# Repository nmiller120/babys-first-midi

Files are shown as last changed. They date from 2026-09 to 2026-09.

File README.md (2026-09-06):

# Baby's First MIDI

A Fisher-Price piano hacked into a MIDI controller while preserving the toy's original functionality.

## Hardware

- Pimoroni Tiny 2350 (RP2350, 3.3 V logic)
- Fisher-Price Kick & Play-style piano
- Teenage Engineering EP-133 K.O. II as the initial MIDI target
- 3.5 mm TRS Type A MIDI output
- Two 10k potentiometers for octave/group and scale selection

## Current controller layout

### Piano keys

Five active-high digital inputs are mapped to the Fisher-Price piano keys:

| Tiny 2350 GPIO | Key |
| --- | --- |
| GP1 | Key 1 |
| GP2 | Key 2 |
| GP3 | Key 3 |
| GP4 | Key 4 |
| GP5 | Key 5 |

The inputs currently use the RP2350 internal pull-downs. A press sends MIDI Note On and releasing the key sends MIDI Note Off. Notes sustain for as long as a key is held, and multiple keys can be held simultaneously for polyphonic MIDI.

The key inputs use a 30 ms software debounce.

### A0 - octave / KO II group selector

A 10k potentiometer connected to A0 (GP26 / ADC0) selects the C-root octave:

| Setting | Root MIDI note | KO II group |
| --- | ---: | --- |
| C2 | 36 | A |
| C3 | 48 | B |
| C4 | 60 | C |
| C5 | 72 | D |

This uses the KO II's fixed MIDI note ranges to make the pot function as a physical A/B/C/D group selector.

### A1 - scale selector

A second 10k potentiometer connected to A1 (GP27 / ADC1) selects the interval mapping for the five keys:

| Setting | Five-key mapping |
| --- | --- |
| Chromatic | C, C#, D, D#, E |
| Major | C, D, E, F, G |
| Minor | C, D, Eb, F, G |
| Minor Pentatonic | C, Eb, F, G, Bb |
| Major Pentatonic | C, D, E, G, A |

The root is always C. The A0 octave selection is added to the interval pattern selected by A1 to produce the final MIDI note.

## Potentiometer calibration and filtering

Bench testing showed that both pots reach approximately 56,000 at the top of their useful ADC range rather than the full 65,535 returned by MicroPython's `read_u16()`.

The selector logic therefore uses a calibrated range:

    POT_ADC_MIN = 1000
    POT_ADC_MAX = 56000

Readings outside that range are clamped to the nearest endpoint. This provides usable dead zones at both physical ends of the pots and ensures the first and last selector positions are easy to reach.

To prevent ADC noise from causing selector chatter near a boundary, two filters are applied:

    POT_HYSTERESIS = 2000
    POT_DEBOUNCE_MS = 150

A pot must first move beyond the hysteresis boundary and then remain in the new discrete state for at least 150 ms before the selection is accepted.

The stable filtered selector state is also used when calculating MIDI notes, so debug output and actual MIDI behavior remain synchronized.

## MIDI output

Tiny 2350 UART0 TX is on GP0. MIDI serial runs at 31,250 baud.

The current 3.3 V MIDI transmitter breadboard is:

    Tiny 2350                     TRS Type A MIDI
    ---------                     ---------------
    3V3 --- 20R --- 10R -------- Ring
    GP0 ----------- 10R -------- Tip
    GND                         (not connected)
                                Sleeve: NC

The 20 ohm + 10 ohm series pair is a temporary 30 ohm approximation to the nominal 33 ohm transmitter resistor used in the 3.3 V MIDI circuit.

IMPORTANT: Verify wiring and polarity before connecting an instrument. The KO II uses TRS MIDI Type A.

## LED behavior

The Tiny 2350 onboard RGB LED is used as a MIDI activity indicator. It lights white while one or more notes are being held and turns off when the final active note is released.

## Debug output

During development, `main.py` prints state changes to the MicroPython console.

Changing the octave/group pot produces output similar to:

    OCTAVE | Octave: C4 | KO II Group: C | Root MIDI Note: 60

Changing the scale pot produces:

    SCALE  | Scale: Minor Pentatonic

Pressing a key reports the complete transformation:

    PRESS | Octave: C4 | KO II Group: C | Scale: Minor Pentatonic | MIDI Note: 67

This makes it possible to verify the pot selection, scale mapping, and resulting MIDI note from Thonny without relying solely on the KO II.

## Tests

The `Tests` directory contains development/bench scripts.

- `Test001.py` - initial UART MIDI and onboard LED test.
- `Test002.py` - periodically prints raw A0/A1 ADC readings and approximate voltages for potentiometer testing and calibration.

## Development status

Current development branch: `feature/pot-scale-selection`.

Completed so far:

- Tiny 2350 MicroPython environment
- 31,250 baud MIDI UART output
- TRS Type A KO II MIDI communication
- Five debounced digital key inputs
- Sustained Note On / Note Off behavior
- Polyphonic key handling
- Onboard MIDI activity LED
- Four-position octave / KO II group selection
- Five-position scale selection
- Potentiometer ADC calibration
- Potentiometer hysteresis and time debounce
- Thonny debug logging

Next major hardware step is integrating the Tiny 2350 inputs with the Fisher-Price key signals while preserving the toy's original functionality.

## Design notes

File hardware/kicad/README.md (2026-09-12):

# Baby's First MIDI — KiCad

KiCad hardware design files for Baby's First MIDI.

The Rev A prototype board is routed on two copper layers, with a filled backside
ground zone. Open `babys-first-midi.kicad_pro` so KiCad loads the project rules and
the `BFM` footprint library from `fp-lib-table`.

## DRC repair, 2026-09-11

Starting from placement-only commit `f590c33`, this revision:

- Moves the RJ45 back to the left side, inside the board outline and clear of the
  MIDI jack; moves the MIDI jack away from the lower-right mounting hole.
- Rotates the five MOSFET footprints to provide separate gate, drain and source
  escape paths, then routes all required connections and refills ground copper.
- Preserves every pad number and net assignment from the starting board.
- Fixes silkscreen overlaps, puts hidden values on F.Fab, and stores all seven
  prototype footprint definitions in the project-local `BFM.pretty` library.
- Saves explicit minimum rules: 0.25 mm copper clearance, 0.25 mm track width,
  0.50 mm copper-to-edge clearance, and 0.15 mm silkscreen clearance. Routes use
  0.30 mm tracks. No DRC exclusions or severity suppressions were added.

Validated with KiCad 10.0.6: **0 violations and 0 unconnected items**.
The machine-readable report is `validation/drc.json`. Reproduce from this folder:

```powershell
kicad-cli pcb drc --refill-zones --format json --exit-code-violations --output validation/drc.json babys-first-midi.kicad_pcb
```

This remains the prototype experiment described in the earlier design work:
the connector footprints remain project-specific draft geometries. The clean
result verifies board geometry and connectivity against the PCB net assignments;
it does not certify the remaining connector fit, enclosure fit or schematic parity.

## Populated 3D view

In PCB Editor, use View > 3D Viewer (Alt+3). Models are attached to the board
and to the project footprint library. Resistors and MOSFETs use KiCad's standard
STEP models; install the KiCad 10 3D model library if these do not appear.
The RJ45 uses a drawing-based model. The WH148 pots and Tiny
2350 now use the bundled drawing-based replacement models. Their geometry,
source drawings and remaining estimates are documented in
`3dmodels/MECHANICAL_NOTES.md`.

The WH148 replacement changes the old 3 mm pitch to 5 mm, with 1.3 mm holes.
Pots mount directly, shafts parallel to the board toward the top edge. The Tiny
footprint's mirrored banks are corrected and the module is rotated and moved
to put USB at the right edge. Routing and ground fill are regenerated while
preserving all numbered pad-to-net assignments. KiCad 10.0.6 DRC reports zero
violations and zero unconnected items; see `validation/drc.json`.

J2 is now the uxcell PJ-320A, using a Keebio STEP model and adapted footprint.
The user-supplied pinout maps MIDI_TIP to pin 4 and MIDI_RING to pin 3; pins 1
(sleeve, as before) and 2 (ring2) are unconnected. The mouth faces the right
edge. See `3dmodels/MECHANICAL_NOTES.md` for source attribution and geometry
limits. The replacement is rerouted and passes DRC with no unconnected items.

J1 now uses BFM:RJ45_FMHXG_AssumedPinout and a drawing-based model, facing the
left edge. The 8 signal holes, 2 locating holes and 2 shield holes follow the
user-supplied drawing. Sequential 1-8 numbering is an explicit prototype
assumption approved by the user, not a verified vendor pinout. Existing numbered
signal nets are preserved; shield pads are unconnected. See
`RJ45_CONTINUITY_CHECK.md` for the precise mapping to check when the parts arrive.
Rerouting and ground refill pass KiCad 10.0.6 DRC: zero violations and zero
unconnected items.

## 2N7000 input buffers

Q1-Q5 now use through-hole 2N7000 MOSFETs with the onsemi 2N7000TA
TO-92 pinout: 1=source (GND), 2=gate (input resistor), 3=drain (GPIO/pull-up).
Datasheet: https://www.onsemi.com/download/data-sheet/pdf/2n7000ta-d.pdf
The local BFM:TO-92_2N7000_SGD footprint derives from KiCad's
TO-92_Inline_Wide footprint. Its 2.54 mm hole spacing requires spreading the
leads; match the flat face to the fabrication outline. The 3D model is the
standard KiCad 10 TO-92_Inline_Wide STEP model.

PCB nets and schematic connections were checked against the previous design
by gate/drain/source function, including the required pin-number remap.
KiCad 10.0.6 DRC reports zero violations and zero unconnected items.
This verifies layout connectivity, not operation with the toy's unmeasured
signal voltage. Verify input switching on the assembled prototype.

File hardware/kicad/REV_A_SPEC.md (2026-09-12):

# Baby's First MIDI — Rev A Electrical Specification

This file is the source-of-truth for the first ERC-checkable KiCad schematic.

## Architecture

External project box. The Pimoroni Tiny 2350 is powered through its onboard USB-C connector.

Signal flow:

Fisher-Price toy -> RJ45 -> 5x MOSFET input buffers -> Tiny 2350 -> TRS MIDI OUT

Two 10k potentiometers connect directly to Tiny 2350 analog inputs.

## RJ45 pin assignment

| RJ45 pin | Signal |
| --- | --- |
| 1 | FPT_C |
| 2 | FPT_D |
| 3 | FPT_E |
| 4 | FPT_F |
| 5 | FPT_G |
| 6 | FPT_COMMON |
| 7 | Spare |
| 8 | Spare |

## Digital input buffers

Five identical 2N7000 channels are used.

For each channel:

- Fisher-Price sense line -> 100k ohm -> 2N7000 gate
- 2N7000 source -> GND
- 2N7000 drain -> Tiny 2350 GPIO
- 3V3 -> 10k ohm pull-up -> drain/GPIO node

This is an inverting open-drain-style buffer stage.

| Key | Tiny 2350 GPIO |
| --- | --- |
| C | GP1 |
| D | GP2 |
| E | GP3 |
| F | GP4 |
| G | GP5 |

## Potentiometers

Both potentiometers are 10k.

| Function | Tiny 2350 pin |
| --- | --- |
| Octave | GP26 / ADC0 / A0 |
| Scale | GP27 / ADC1 / A1 |

Each pot is wired as a 3.3V-to-GND divider with the wiper going to the ADC input.

## MIDI OUT

UART0 TX is GP0 at 31,250 baud.

TRS Type A output:

- 3V3 -> 33 ohm -> Ring
- GP0 -> 33 ohm -> Tip
- Sleeve -> NC

## Power

The Tiny 2350 is powered only through its onboard USB-C connector for Rev A.

No Fisher-Price power is brought into the project box.

## Schematic intent

The KiCad schematic should contain:

- J1: 8-pin RJ45 female connector
- Q1-Q5: 2N7000
- R1-R5: 100k gate resistors
- R6-R10: 10k GPIO pull-ups
- U1: Pimoroni Tiny 2350 module/header representation
- RV1: 10k octave potentiometer
- RV2: 10k scale potentiometer
- R11-R12: 33 ohm MIDI series resistors
- J2: 3.5mm TRS jack
- Explicit 3V3 and GND nets
- No-connect markers on unused RJ45 pins and TRS sleeve where appropriate

Before Gerber generation, the schematic must pass ERC with no unexplained errors and the PCB must pass DRC with no unexplained errors.

## 2N7000 input buffers

Q1-Q5 now use through-hole 2N7000 MOSFETs with the onsemi 2N7000TA
TO-92 pinout: 1=source (GND), 2=gate (input resistor), 3=drain (GPIO/pull-up).
Datasheet: https://www.onsemi.com/download/data-sheet/pdf/2n7000ta-d.pdf
The local BFM:TO-92_2N7000_SGD footprint derives from KiCad's
TO-92_Inline_Wide footprint. Its 2.54 mm hole spacing requires spreading the
leads; match the flat face to the fabrication outline. The 3D model is the
standard KiCad 10 TO-92_Inline_Wide STEP model.

PCB nets and schematic connections were checked against the previous design
by gate/drain/source function, including the required pin-number remap.
KiCad 10.0.6 DRC reports zero violations and zero unconnected items.
This verifies layout connectivity, not operation with the toy's unmeasured
signal voltage. Verify input switching on the assembled prototype.

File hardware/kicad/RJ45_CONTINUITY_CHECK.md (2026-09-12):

# J1 prototype pinout assumption

Selected part: FMHXG RJ45NMCCFC-90D-10, Amazon B0BRQ2R8HW.
The user approved fitting and routing the connector before physical continuity
verification. Geometry follows the supplied component-side drawing. The related
CKMTW family is a reference, not proof of the FMHXG internal wiring.

Numbering is explicitly assumed sequentially across the staggered terminals:
component side viewed from above, connector mouth toward the TOP of this diagram.
This is not a pinout extracted from a verified FMHXG or CKMTW CAD library.

```text
                   MOUTH
       SH                       SH
           locating     locating

             2    4    6    8       nearer the mouth
          1    3    5    7          rear row
```

Coordinates in mm, origin at front mouth center, X right and Y toward rear:

| Assumed contact | X | Y | Board net |
|---|---:|---:|---|
| 1 | -4.445 | 16.79 | FPT_C |
| 2 | -3.175 | 14.25 | FPT_D |
| 3 | -1.905 | 16.79 | FPT_E |
| 4 | -0.635 | 14.25 | FPT_F |
| 5 | 0.635 | 16.79 | FPT_G |
| 6 | 1.905 | 14.25 | FPT_COMMON |
| 7 | 3.175 | 16.79 | Unconnected |
| 8 | 4.445 | 14.25 | Unconnected |

Both shield pads are unconnected. On the carrier the mouth faces LEFT; rotate
the diagram 90 degrees counterclockwise to match the board's top view.

Before PCB ordering, insert a numbered RJ45 breakout plug or known cable into
one loose jack. With a continuity meter, record which solder terminal connects
to each plug contact 1 through 8. Use the breakout's numbering; wire colors alone
can be misleading without knowing its wiring standard. Also check shield tabs
to metal shell, and test-fit the terminal, peg and shield-hole pattern at 1:1.
If the mapping differs, change the footprint numbering and reroute before
manufacture. The clean DRC report does not validate this physical assumption.

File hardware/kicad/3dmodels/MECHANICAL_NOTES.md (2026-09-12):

# Drawing-based replacement models

The WH148 potentiometers and Tiny 2350 now use custom drawing-based models.
The RJ45 now uses a model and footprint built from the supplied mechanical
drawing. Its contact numbering is a user-approved prototype assumption pending
physical checking; see ../RJ45_CONTINUITY_CHECK.md.

## WH148 potentiometers

Source: user's mechanical drawing for the EEEEE kit, Amazon ASIN B0FGD497QN.
The drawing specifies 5 mm terminal pitch, 1.0 x 0.4 mm terminals, a 16.5 mm
housing, 17 mm front plate, 9.2 mm rear-to-shaft datum length, 15 +/- 0.5 mm
shaft length, 6 mm shaft diameter, 18 knurl teeth and an M7 x 0.75 bushing.

The new BFM:WH148_Horizontal_P5.00mm footprint uses 1.3 mm round finished holes
and 2.5 mm pads. These are chosen hole/pad sizes, not manufacturer land-pattern
recommendations. Pin numbers follow the supplied shaft-end view. All existing
pad-to-net assignments are preserved. Direct mounting puts the shafts parallel
to the board, pointing toward its top edge. Pots are 20 mm apart.

Model coordinates: middle terminal at X/Y zero, shaft toward +Y, carrier top
Z=0. A 0.5 mm substrate-to-board seating gap is assumed. Detailed metal tabs,
substrate contours and bends are approximate; thread crests are cosmetic rings.
Model clearances do not account for the user's knob size, enclosure or nuts.

## Tiny 2350

Sources:
- https://shop.pimoroni.com/products/tiny-2350
- https://cdn.shopify.com/s/files/1/0174/1800/files/tiny-2350-mechanical-diagram.pdf?v=1725452657
- https://cdn.shopify.com/s/files/1/0174/1800/files/tiny2350_pinout_diagram.pdf?v=1723124465

The model has an 18 x 21.3 mm PCB, 2.54 mm pitch and 15.24 mm header-bank spacing.
The carrier footprint's previously mirrored banks are corrected. With USB up,
GP0-GP7 run down the right bank, and VBUS/GND/3V3/A3/A2/A1/A0/GND down the left.
On this carrier the module is rotated with USB facing the right board edge.
The module center is (127.25,58) mm. The model includes switches, Qw/ST socket,
USB shell, castellations, labels and underside components.

The mounted model assumes 2.54 mm male header spacers and lifts the bare module
2.54 mm above the carrier. The PCB thickness, component heights, USB internals
and fine details absent from the drawing are visual estimates. This is custom
CAD, not a manufacturer-supplied STEP model or an enclosure-fit certification.

## PJ-320A MIDI jack

J2 now uses the Keebio PJ-320A STEP and a locally adapted footprint:
https://github.com/keebio/Keebio-Parts.pretty/blob/master/3dmodels/PJ-320A.step
https://github.com/keebio/Keebio-Parts.pretty/blob/master/TRRS-PJ-320A.kicad_mod
The MIT license is preserved in LICENSE-Keebio.txt.

The user's supplied uxcell pinout identifies sleeve=1, tip=4, ring1=3, ring2=2.
This overrides the tip/ring2 labels in the upstream footprint. Pin 4 carries
MIDI_TIP and pin 3 carries MIDI_RING. Ring2 (pin 2) is unused; sleeve (pin 1)
remains unconnected, preserving the old design's sleeve treatment. No claim
of complete MIDI electrical compliance or schematic parity is made here.

The footprint retains four plated slots and two locating holes from Keebio.
Its outline was adapted to clear solder mask and the board edge. The connector
faces right at (138,86) mm, with the mouth at the board edge. Its 3D geometry
and locating-hole dimensions come from the community model, not an uxcell
dimensional drawing. The supplied image establishes the electrical pinout.

## Validation

KiCad 10.0.6 loads the board and renders the bundled models. All 26 components
and signal connections are preserved by function (J2 and Q1-Q5 use remapped pin numbers). J2's original tip/ring
nets are remapped by function to pins 4/3. The corrected pad geometry was
rerouted and ground copper refilled. validation/drc.json
reports zero violations and zero unconnected items. Schematic parity and the
remaining draft connector footprints are outside this verification.

## 2N7000 input buffers

Q1-Q5 now use through-hole 2N7000 MOSFETs with the onsemi 2N7000TA
TO-92 pinout: 1=source (GND), 2=gate (input resistor), 3=drain (GPIO/pull-up).
Datasheet: https://www.onsemi.com/download/data-sheet/pdf/2n7000ta-d.pdf
The local BFM:TO-92_2N7000_SGD footprint derives from KiCad's
TO-92_Inline_Wide footprint. Its 2.54 mm hole spacing requires spreading the
leads; match the flat face to the fabrication outline. The 3D model is the
standard KiCad 10 TO-92_Inline_Wide STEP model.

PCB nets and schematic connections were checked against the previous design
by gate/drain/source function, including the required pin-number remap.
KiCad 10.0.6 DRC reports zero violations and zero unconnected items.
This verifies layout connectivity, not operation with the toy's unmeasured
signal voltage. Verify input switching on the assembled prototype.

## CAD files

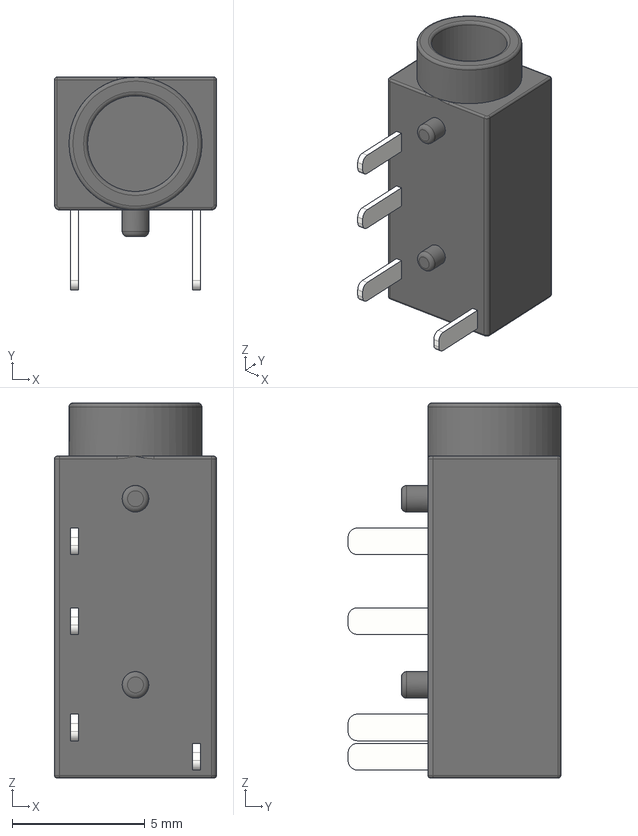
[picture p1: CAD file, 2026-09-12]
hardware/kicad/3dmodels/PJ-320A.step
6.10 x 8.00 x 14.1 mm

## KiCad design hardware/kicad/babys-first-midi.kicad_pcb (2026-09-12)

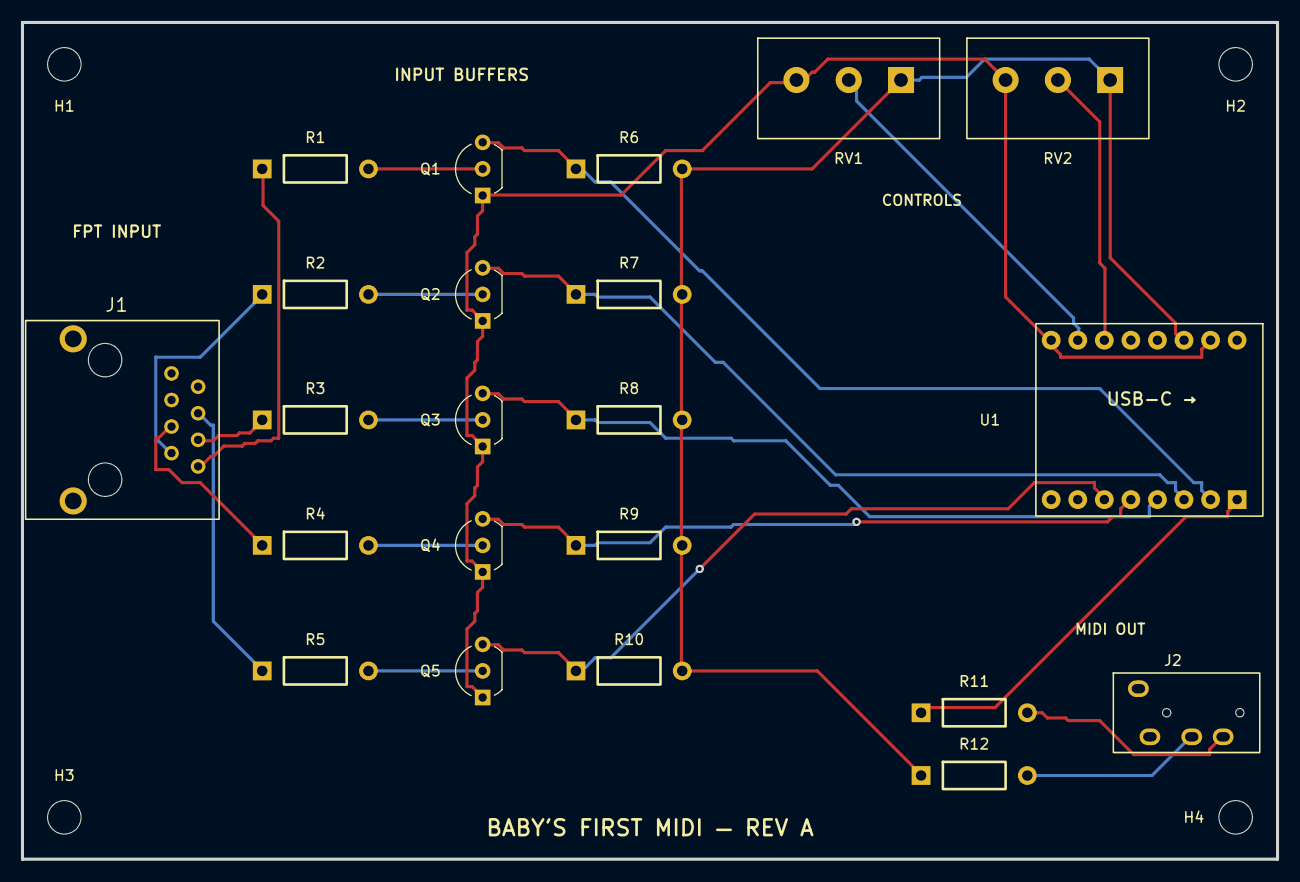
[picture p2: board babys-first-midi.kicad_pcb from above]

Board: 2 copper layers, 120.0 x 80.0 mm, 26 parts (0 on the bottom side), 22 nets.

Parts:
H1, H2, H3, H4: MountingHole_3.2mm_M3
J1: RJ45NMCCFC-90D-10; RJ45_FMHXG_AssumedPinout
J2: PJ-320A; PJ320A_Uxcell_Horizontal
Q1, Q2, Q3, Q4, Q5: 2N7000; TO-92_2N7000_SGD
R1, R2, R3, R4, R5: 100k; Axial_10.16mm
R6, R7, R8, R9, R10: 10k; Axial_10.16mm
R11, R12: 33; Axial_10.16mm
RV1, RV2: 10k; WH148_Horizontal_P5.00mm
U1: BFM:Pimoroni_Tiny2350_2x8_Header; Pimoroni_Tiny2350_2x8_Header

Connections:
3V3: R6.2, R7.2, R8.2, R9.2, R10.2, R12.1, RV1.1, RV2.1, U1.11
ADC_OCTAVE: RV1.2, U1.15
ADC_SCALE: RV2.2, U1.14
FPT_C: J1.1, R1.1
FPT_D: J1.2, R2.1
FPT_E: J1.3, R3.1
FPT_F: J1.4, R4.1
FPT_G: J1.5, R5.1
GATE_C: Q1.2, R1.2
GATE_D: Q2.2, R2.2
GATE_E: Q3.2, R3.2
GATE_F: Q4.2, R4.2
GATE_G: Q5.2, R5.2
GND: Q1.1, Q2.1, Q3.1, Q4.1, Q5.1, RV1.3, RV2.3, U1.10, U1.16
KEY_C: Q1.3, R6.1, U1.2
KEY_D: Q2.3, R7.1, U1.3
KEY_E: Q3.3, R8.1, U1.4
KEY_F: Q4.3, R9.1, U1.5
KEY_G: Q5.3, R10.1, U1.6
MIDI_RING: J2.3, R12.2
MIDI_TIP: J2.4, R11.2
MIDI_TX: R11.1, U1.1

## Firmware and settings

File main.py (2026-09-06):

from machine import UART, Pin, ADC
from time import sleep_ms, ticks_ms, ticks_diff

# MIDI 1.0 serial: 31,250 baud, 8-N-1.
# Tiny 2350: UART0 TX on GP0.
midi = UART(
    0,
    baudrate=31250,
    tx=Pin(0)
)

MIDI_CHANNEL = 1
MIDI_VELOCITY = 100
DEBOUNCE_MS = 30

# Calibrated usable range of both 10k potentiometers.
# Clamp the physical end regions so every selector position is easy to reach.
POT_ADC_MIN = 1000
POT_ADC_MAX = 56000
POT_HYSTERESIS = 2000
POT_DEBOUNCE_MS = 150

# Tiny 2350 onboard RGB LED is on GP18-GP20 and is active-low.
led_r = Pin(18, Pin.OUT, value=1)
led_g = Pin(19, Pin.OUT, value=1)
led_b = Pin(20, Pin.OUT, value=1)

# Tiny 2350 analog inputs.
# A0 = GP26 / ADC0
# A1 = GP27 / ADC1
octave_pot = ADC(26)
scale_pot = ADC(27)

# A0 selects the C-root octave. These line up with the KO II's
# four fixed MIDI note groups:
# C2=36 -> Group A
# C3=48 -> Group B
# C4=60 -> Group C
# C5=72 -> Group D
OCTAVE_ROOTS = (
    ("C2", "A", 36),
    ("C3", "B", 48),
    ("C4", "C", 60),
    ("C5", "D", 72),
)

# A1 selects the interval pattern used by the five keys.
# Intervals are semitones above the selected C root.
SCALES = (
    ("Chromatic",       (0, 1, 2, 3, 4)),
    ("Major",           (0, 2, 4, 5, 7)),
    ("Minor",           (0, 2, 3, 5, 7)),
    ("Minor Pentatonic",(0, 3, 5, 7, 10)),
    ("Major Pentatonic",(0, 2, 4, 7, 9)),
)

# Fisher-Price keys are expected to be active-high.
# Internal pull-downs keep the inputs defined during jumper testing.
BUTTON_GPIOS = (1, 2, 3, 4, 5)


def set_led(on):
    # White when any note is active. Active-low outputs.
    value = 0 if on else 1
    led_r.value(value)
    led_g.value(value)
    led_b.value(value)


def note_on(note, velocity=MIDI_VELOCITY, channel=MIDI_CHANNEL):
    status = 0x90 | ((channel - 1) & 0x0F)
    midi.write(bytes((status, note, velocity)))


def note_off(note, velocity=0, channel=MIDI_CHANNEL):
    status = 0x80 | ((channel - 1) & 0x0F)
    midi.write(bytes((status, note, velocity)))


def pot_index(adc, option_count):
    """
    Return the raw selector region with no hysteresis.
    Used only to establish the initial selector state at startup.
    """
    raw = adc.read_u16()
    raw = max(POT_ADC_MIN, min(raw, POT_ADC_MAX))

    span = POT_ADC_MAX - POT_ADC_MIN
    normalized = raw - POT_ADC_MIN

    index = (normalized * option_count) // (span + 1)
    return min(index, option_count - 1)


def hysteresis_index(adc, option_count, current_index):
    """
    Update a discrete pot selector using hysteresis around each boundary.

    The knob must move POT_HYSTERESIS counts past a boundary before the
    state changes. Once changed, it must move back past the opposite side
    of that deadband before changing back.
    """
    raw = adc.read_u16()
    raw = max(POT_ADC_MIN, min(raw, POT_ADC_MAX))

    span = POT_ADC_MAX - POT_ADC_MIN
    region_width = span / option_count

    # Allow large knob movements to cross more than one state in one pass.
    while current_index < option_count - 1:
        upper_boundary = POT_ADC_MIN + ((current_index + 1) * region_width)
        if raw >= upper_boundary + POT_HYSTERESIS:
            current_index += 1
        else:
            break

    while current_index > 0:
        lower_boundary = POT_ADC_MIN + (current_index * region_width)
        if raw <= lower_boundary - POT_HYSTERESIS:
            current_index -= 1
        else:
            break

    return current_index


def note_for_key(key_index):
    octave_name, ko2_group, root_note = OCTAVE_ROOTS[last_octave_index]
    scale_name, intervals = SCALES[last_scale_index]
    note = root_note + intervals[key_index]

    return note, octave_name, ko2_group, scale_name


buttons = []
active_notes = set()

# Track selector states so debug output only prints when a pot crosses
# into a different discrete setting.
last_octave_index = pot_index(octave_pot, len(OCTAVE_ROOTS))
last_scale_index = pot_index(scale_pot, len(SCALES))

octave_candidate_index = last_octave_index
scale_candidate_index = last_scale_index
octave_candidate_since = ticks_ms()
scale_candidate_since = ticks_ms()

octave_name, ko2_group, _ = OCTAVE_ROOTS[last_octave_index]
scale_name, _ = SCALES[last_scale_index]

print(
    "OCTAVE | Octave: {} | KO II Group: {}".format(
        octave_name, ko2_group
    )
)
print("SCALE  | Scale: {}".format(scale_name))

for key_index, gpio in enumerate(BUTTON_GPIOS):
    pin = Pin(gpio, Pin.IN, Pin.PULL_DOWN)
    initial_state = pin.value()

    buttons.append({
        "pin": pin,
        "key_index": key_index,
        "raw_state": initial_state,
        "stable_state": initial_state,
        "changed_at": ticks_ms(),
        # Remember the exact note started by this key so Note Off still
        # targets the correct note if either pot moves while it is held.
        "active_note": None,
    })


while True:
    now = ticks_ms()

    octave_index = hysteresis_index(
        octave_pot, len(OCTAVE_ROOTS), last_octave_index
    )

    if octave_index != octave_candidate_index:
        octave_candidate_index = octave_index
        octave_candidate_since = now

    if (
        octave_candidate_index != last_octave_index
        and ticks_diff(now, octave_candidate_since) >= POT_DEBOUNCE_MS
    ):
        last_octave_index = octave_candidate_index
        octave_name, ko2_group, root_note = OCTAVE_ROOTS[last_octave_index]
        print(
            "OCTAVE | Octave: {} | KO II Group: {} | Root MIDI Note: {}".format(
                octave_name, ko2_group, root_note
            )
        )

    scale_index = hysteresis_index(
        scale_pot, len(SCALES), last_scale_index
    )

    if scale_index != scale_candidate_index:
        scale_candidate_index = scale_index
        scale_candidate_since = now

    if (
        scale_candidate_index != last_scale_index
        and ticks_diff(now, scale_candidate_since) >= POT_DEBOUNCE_MS
    ):
        last_scale_index = scale_candidate_index
        scale_name, _ = SCALES[last_scale_index]
        print("SCALE  | Scale: {}".format(scale_name))

    for button in buttons:
        raw_state = button["pin"].value()

        # A raw transition starts/restarts this button's debounce timer.
        if raw_state != button["raw_state"]:
            button["raw_state"] = raw_state
            button["changed_at"] = now

        # Accept a new state only after it remains unchanged for DEBOUNCE_MS.
        if (
            raw_state != button["stable_state"]
            and ticks_diff(now, button["changed_at"]) >= DEBOUNCE_MS
        ):
            button["stable_state"] = raw_state

            if raw_state:
                # Read both pots at the instant the key is pressed.
                note, octave_name, ko2_group, scale_name = note_for_key(
                    button["key_index"]
                )
                button["active_note"] = note

                print(
                    "PRESS | Octave: {} | KO II Group: {} | Scale: {} | MIDI Note: {}".format(
                        octave_name,
                        ko2_group,
                        scale_name,
                        note,
                    )
                )

                note_on(note)
                active_notes.add(note)
            else:
                note = button["active_note"]

                if note is not None:
                    note_off(note)
                    active_notes.discard(note)
                    button["active_note"] = None

            # Keep the LED lit while one or more notes are sustained.
            set_led(bool(active_notes))

    # Independent debounce keeps simultaneous key presses polyphonic.
    sleep_ms(1)

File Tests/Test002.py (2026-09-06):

from machine import ADC
from time import sleep_ms

# Tiny 2350 analog inputs:
# A0 = GP26 / ADC0
# A1 = GP27 / ADC1
a0 = ADC(26)
a1 = ADC(27)

PRINT_INTERVAL_MS = 250


def voltage(raw):
    # MicroPython read_u16() scales the ADC result to 0..65535.
    # The Tiny 2350 ADC reference is nominally 3.3 V.
    return raw * 3.3 / 65535


print("Potentiometer test started")
print("Turn A0 and A1. Press Ctrl+C to stop.")
print()

while True:
    a0_raw = a0.read_u16()
    a1_raw = a1.read_u16()

    print(
        "A0: {:5d} ({:.2f} V)    A1: {:5d} ({:.2f} V)".format(
            a0_raw,
            voltage(a0_raw),
            a1_raw,
            voltage(a1_raw),
        )
    )

    sleep_ms(PRINT_INTERVAL_MS)

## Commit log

2026-09-06 Add project hardware and wiring notes
2026-09-06 Add Test001 MIDI and LED test
2026-09-06 Map five buttons to debounced MIDI scale notes
2026-09-06 Add pull-down inputs, LED activity, and held-note sustain
2026-09-06 Add Test002 potentiometer ADC monitor
2026-09-06 Calibrate potentiometer selector range
2026-09-06 Document pot selectors and current controller development
2026-09-09 Initialize KiCad project
2026-09-09 Define Rev A PCB schematic architecture
    [babys-first-midi.kicad_sch]
2026-09-09 Build KiCad 10 Rev A electrical schematic
    [babys-first-midi.kicad_sch]
2026-09-09 Wire Rev A schematic connections
    [babys-first-midi.kicad_sch]
2026-09-09 Fix KiCad wire segment syntax
    [babys-first-midi.kicad_sch]
2026-09-10 Assign prototype through-hole footprints
    [babys-first-midi.kicad_sch]
2026-09-10 Create routed Rev A prototype PCB
    [babys-first-midi.kicad_pcb]
2026-09-10 Target KiCad 10 PCB file format
    [babys-first-midi.kicad_pcb]
2026-09-10 Use full 16-pin Tiny 2350 socket footprint
    [babys-first-midi.kicad_pcb]
2026-09-10 Move Tiny 2350 for resistor clearance
    [babys-first-midi.kicad_pcb]
2026-09-10 Rotate Tiny 2350 USB-C toward right edge
    [babys-first-midi.kicad_pcb]
2026-09-10 Reroute rotated Tiny 2350 connections
    [babys-first-midi.kicad_pcb]
2026-09-10 Rebuild PCB routing for DRC clearance
    [babys-first-midi.kicad_pcb]
2026-09-10 Separate PCB routing into dedicated net corridors
    [babys-first-midi.kicad_pcb]
2026-09-10 Rework PCB placement for clean routing
    [babys-first-midi.kicad_pcb]
2026-09-12 Resolve PCB DRC with complete routing and project footprint library
    Restore connector placement, rotate MOSFETs, connect all nets, and refill ground. Clean silkscreen and package draft footprints with explicit clearance rules.
    KiCad 10.0.6: zero DRC violations and zero unconnected items. Preserve all original pad net assignments; include report and prototype limitations.
    [babys-first-midi.kicad_pcb]
2026-09-12 Restore complete PCB file after truncated upload
    Replace the corrupted track/zone data with the complete KiCad-validated board. Verify the uploaded blob hash against the local file. KiCad 10.0.6 DRC: zero violations and zero unconnected items.
    [babys-first-midi.kicad_pcb]
2026-09-12 Add populated 3D board view with standard and illustrative component models
    Attach standard resistor and TO-220 models and bundle illustrative connector, potentiometer and socketed module VRML models. Document model limitations. Copper and placement unchanged; KiCad 10.0.6 D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
    [babys-first-midi.kicad_pcb]
2026-09-12 Fit WH148 pots and correct Tiny 2350 pin banks with drawing-based models
    Replace 3 mm pot pads with 5 mm pitch and 1.3 mm holes for direct horizontal mounting. Correct the Tiny module banks, orient USB toward the right edge, and attach detailed drawing-based models. Reroute and refill while preserving all 26 components and numbered pad net assignments.
    KiCad 10.0.6: zero DRC violations and zero unconnected items. Document sources, assumed assembly heights, and remaining connector model limitations.
    [babys-first-midi.kicad_pcb]
2026-09-12 Replace MIDI jack with PJ-320A footprint and STEP model
    Apply the supplied uxcell pinout: pin 4 MIDI_TIP, pin 3 MIDI_RING, pin 2 unused and pin 1 sleeve unconnected as in the prior design. Adapt Keebio's footprint silkscreen, preserve its MIT attribution, and place the jack opening at the right board edge.
    Reroute and refill copper. KiCad 10.0.6 reports zero violations and zero unconnected items; all connections outside J2 and all 26 components are preserved. Document the community model's mechanical verification limits.
    [PJ-320A.step, babys-first-midi.kicad_pcb]
2026-09-12 Fit drawing-based RJ45 connector with documented prototype pinout
    Replace J1's placeholder with the FMHXG mechanical footprint and custom 3D model, facing the left board edge. Use the user-approved provisional sequential contact numbering and preserve existing numbered signal nets. Leave shield pads unconnected and include an exact continuity-check guide for verification when the physical parts arrive.
    Reroute and refill. KiCad 10.0.6 reports zero violations and zero unconnected items; all 26 components and existing numbered pad net assignments are preserved. Physical contact numbering remains an assumption, not a verified manufacturer pinout.
    [babys-first-midi.kicad_pcb]
2026-09-12 Replace input MOSFETs with through-hole 2N7000 TO-92 parts
    Replace Q1-Q5 IRLZ44N packages with local TO-92 footprints at 2.54 mm lead spacing and standard KiCad 3D models. Remap source/gate/drain to pins 1/2/3 in PCB and embedded schematic symbol while preserving connections by function. Reroute and refill the PCB.
    Verified all component PCB net assignments and before/after schematic netlists with the functional pin remap. KiCad 10.0.6 DRC: zero violations, zero unconnected items.
    [babys-first-midi.kicad_pcb, babys-first-midi.kicad_sch]
